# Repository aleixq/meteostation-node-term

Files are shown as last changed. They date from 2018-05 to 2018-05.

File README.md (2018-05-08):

# MeteoStation-Node-Term
This is a Project to create a weather station, it's based in code from sparkfun by Nathan Seidle, but expanded to make it work to provide a station with its lcd display to show the sensors values. This station also send via serial the sensors data in JSON to a NodeMCU - *the Meteonode* -and it provides a web server to read the data in json (at http://meteoNodeIP:meteoNodePort/getMeteoData), a second nodemcu  - *the Meteoterm* - will connect to the server and will obtain de the sensors values and with these it will calculate some extra information, forecast, pressure history, wind in a polar graphic... And it will be displayed in a tft small screen.

The wifi credentials must be provided in meteonode and meteoterm (an example is provided on each project as wifi-credentials.h.example) move to copy to wifi-credentials.h on each project before builing and uploading the projects.

I build this projects using arduino-makefile from http://hardwarefun.com/tutorials/compiling-arduino-sketches-using-makefile instead of arduino IDE, with some tweaks it can be easy to be ran by IDE.

# Meteostation
BOM:
- Arduino Mega.
- BME280 Pressure sensor.
- SPARKFUn Weather Shield (for wind and rain as pressure temps was a pain...).
- LCD 20x4.

# Meteonode
BOM:
- NodeMCU (linked via serial to MEGA).
- Bidirectional level shifter(3V3 <--> 5V). (to make 5V arduino mega serial pins be reduced to 3V3).

# Meteoterm
BOM:
- NodeMCU 
- ILI9341 Touch screen.
Explained in respective project directory.

# TODO
Add 3d freecad files for cases. 
Add fritzing connections.
Move functions to own classes(as is separated) (yes i have to fulfill the transition from ino to cpp, but this project once upon a time was a simple ino file).
Use E-Ink display in meteoterm to save energy.
Use battery on meteoterm.
Transition to a less energy drainer putting nodemcu in sleep mode, and relax the polling.

# Kudos
big kudos to authors of: 
- Great bme library, from which I have copy some code https://github.com/finitespace/BME280 .
- Another zambretti based forecaster https://github.com/hes19073/hesweewx/blob/0415b182d2318f85cefb9727da630fbe42fab9c9/bin/user/forecast.py 
- A great forecaster https://github.com/fandonov/weatherstation , including zambretti interpretation.
- Zambretti js code of http://www.beteljuice.co.uk/zambretti/forecast.html (the inspiration and the basis of the forecast algorithm in meteoterm.
- Zambretti first forecaster: https://web.archive.org/web/20110610213848/http://www.meteormetrics.com/zambretti.htm
- Ntp code from https://www.geekstips.com/arduino-time-sync-ntp-server-esp8266-udp/
- Great timelib libs: https://github.com/PaulStoffregen/Time 
- Great GFX code from adafruit https://learn.adafruit.com/adafruit-gfx-graphics-library

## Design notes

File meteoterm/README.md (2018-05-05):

#Terminal d'estació meterològica.
La unitat té un historial de pressió (12hores/4preses) registrada a la memòria
Flash. Quan es reinicia hauria de llegir l'historial de la memòria, així que
no hi ha problema en reiniciar.
L'historial serveix per fer un càlcul de la predicció seguint l'algorisme de
Zambretti.
## Funcionament
A intervals regulars (defecte 5seg). Fa una consulta a l'adreça de l'estació
meteorològica (mdns,hostname=meteonode) que s'hagi descobert a la mateixa xarxa,
la consulta que fa és (http://meteoNodeIP:meteoNodePort)/getMeteoData?time=now.
Un cop feta la consulta el meteonode envia les dades que els sensors han llegit,
en json, ho rebem i renderitzem els valors a la pantalla. Quan hem acabat guardo
a la memòria flash la història, hagi canviat o no.

## Hora
l'agafa de NTP cada 5 minuts.

## Historial:
Inici -> [Llegeix de la flash els registres guardats] ->
Demana lectura al meteonode -> tenint la Lectura comprova si la que hi ha a la
flash(fitxer history.json)és anterior a un interval (per defecte 12h/4samples
això és 3/6/9/12), si ho és fes correr tot l'historial una posició:
Clau    Valor
3       Descarta
2       valor de 1
1       valor de 0
0       valor llegit

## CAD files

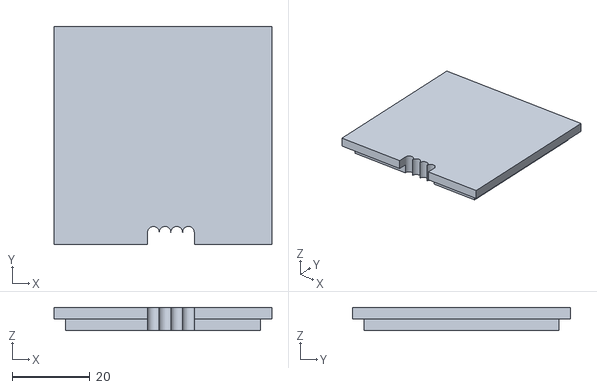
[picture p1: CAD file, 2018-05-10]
3D-dissenys/meteonode-lid.stl
56.0 x 56.0 x 6.00

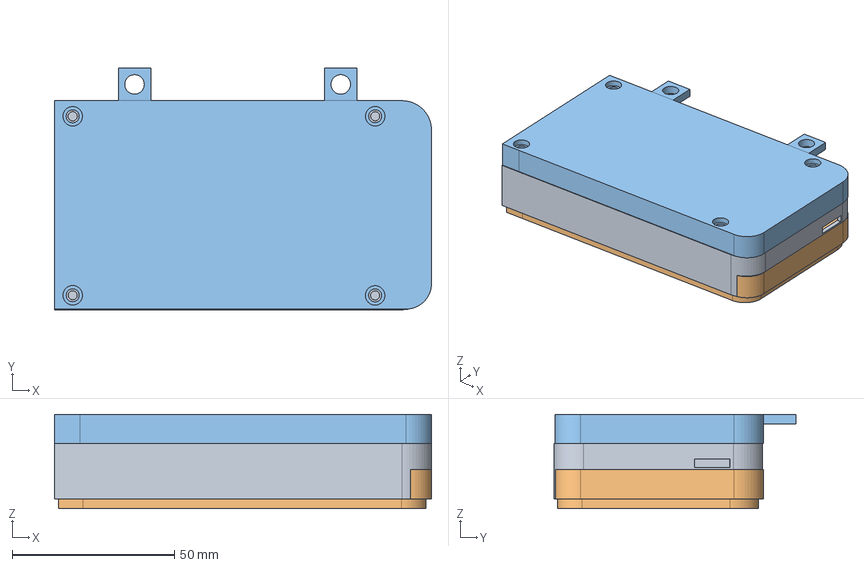
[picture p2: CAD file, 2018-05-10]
3D-dissenys/meteostation-lcd.fcstd
116.0 x 74.4 x 29.0 mm
Fusion-End

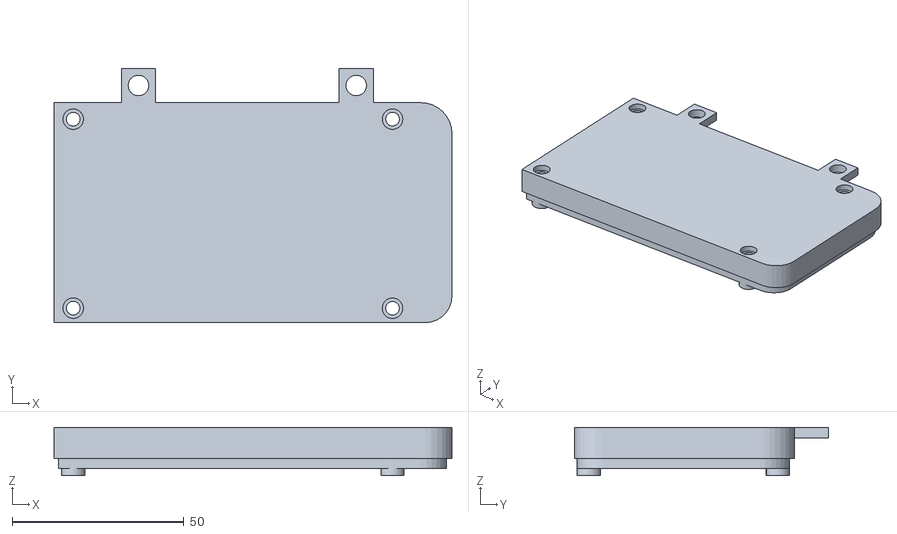
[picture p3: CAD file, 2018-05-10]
3D-dissenys/meteostation-lcd-backplate.stl
116.0 x 74.1 x 14.0

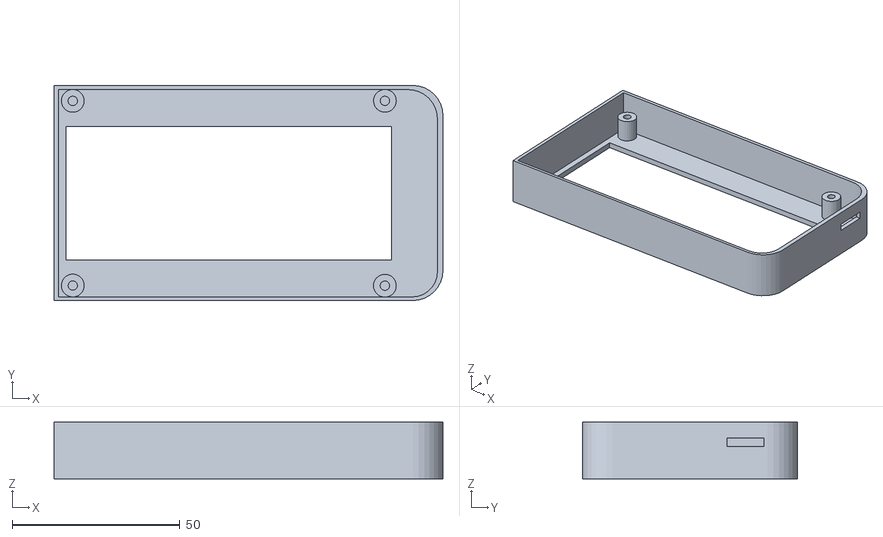
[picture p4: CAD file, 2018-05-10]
3D-dissenys/meteostation-lcd-body.stl
116.0 x 64.2 x 17.0

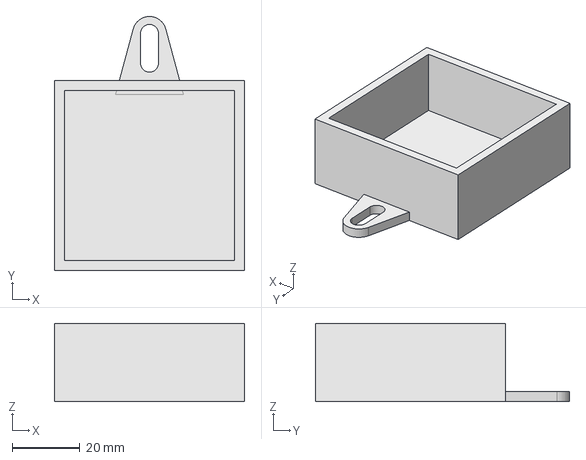
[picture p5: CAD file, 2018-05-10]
3D-dissenys/meteonode-box.fcstd
56.0 x 74.8 x 23.0 mm

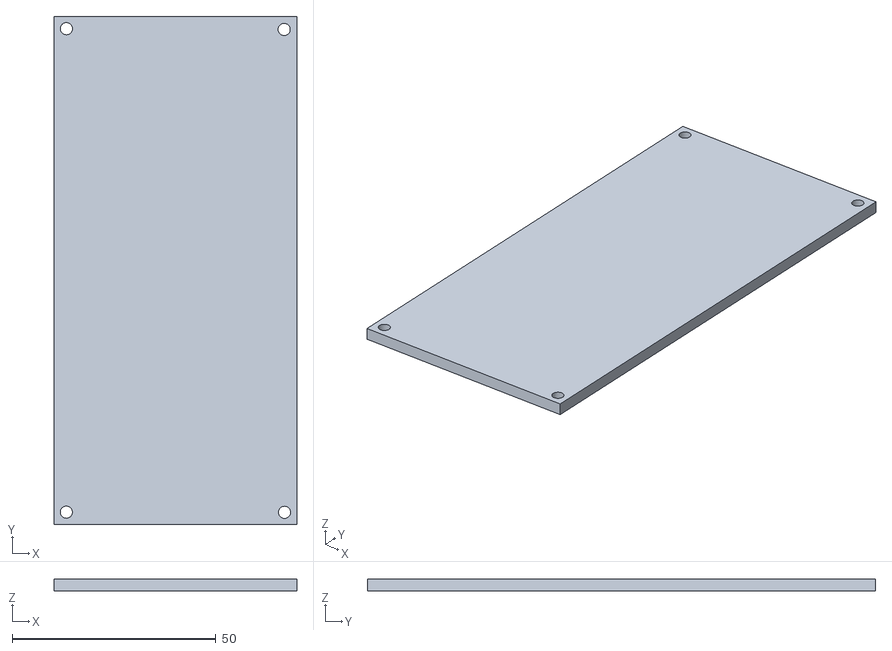
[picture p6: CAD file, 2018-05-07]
3D-dissenys/meteoterm_box_back.stl
59.6 x 124.7 x 3.00

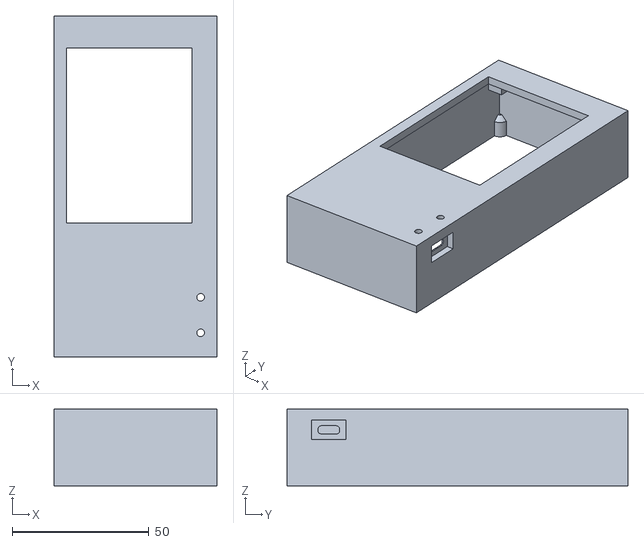
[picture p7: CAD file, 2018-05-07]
3D-dissenys/meteoterm_box.stl
59.6 x 124.7 x 28.0

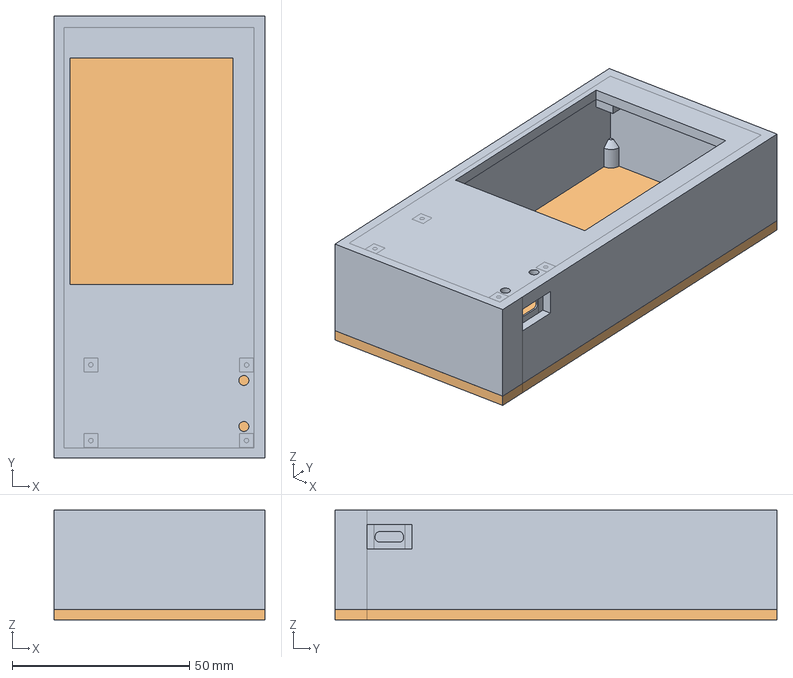
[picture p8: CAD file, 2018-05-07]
3D-dissenys/meteoterm--ili79341-Nodemcu.fcstd
59.6 x 124.7 x 31.0 mm
Fusion-Box (Mirror #1)
Backplate

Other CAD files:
3D-dissenys/meteonode-box.stl

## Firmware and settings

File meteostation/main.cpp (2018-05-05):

/*
 Weather Shield Station
 By: Aleix Quintana Alsius
 Date: May 5th, 2018
 Weather shield to serial to comunicate with esp8266 to propagate data
 License: This code is public domain but you buy me a beer if you use this and we meet someday (Beerware license).

 Much of this is based on Mike Grusin's USB Weather Board code: https://www.sparkfun.com/products/10586, and later Nathan Seidle

 This code reads all the various sensors (wind speed, direction, rain gauge, humidty, pressure, light, batt_lvl)
 and reports it over the serial comm port. This can be easily routed to an datalogger (such as OpenLog) or
 a wireless transmitter (such as Electric Imp).

 Measurements are reported once a second but windspeed and rain gauge are tied to interrupts that are
 calcualted at each report.

 This example code assumes the GPS module is not used.

*/
#include <SoftwareSerial.h>
#include <Arduino.h>
#include <Wire.h>
#include "Screen.h"
#include "Meteo.h"

const byte rxPin = 15; // Wire this to Tx Pin of ESP8266
const byte txPin = 14; // Wire this to Rx Pin of ESP8266

// We'll use a software serial interface to connect to ESP8266
SoftwareSerial ESP8266 (rxPin, txPin);




#define FAKE_WINDIRQ  //TODO , IRQ REMAP  because we use CC3000, look for "TODO" to watch how.
int DEBUG = 1;      // DEBUG counter; if set to 1, will write values back via serial


#include <avr/wdt.h> //We need watch dog for this program


#define IDLE_TIMEOUT_MS  3000 // Amount of time to wait (in milliseconds) with no data
// received before closing the connection.  If you know the server
// you're accessing is quick to respond, you can reduce this value.

#define REFRESH_DATA 1000
#define REFRESH_LCD 5000

/** SCREEN VARS **/
long lastTimeLcd; //The millis lcd counter
//Create lcd object with 0x3F direction -> 20 columns x 4 rows
LiquidCrystal_I2C lcd(0x3F, 20, 4);
//LiquidCrystal_I2C lcd(0x27,16,2);

#define LCD_ROWS_TOPRINT 4
String lcdOut[LCD_ROWS_TOPRINT] = { "T-Pr-W", "VENT", "H-PL", "conMSG" };
int curScreen = 0;
/** END OF SCREEN VARS **/


/* WEATHER VARS */
// Pressure sensor
Adafruit_BME280 bme;
//Hardware pin definitions
//-=-=-=-=-=-=-=-=-=-=-=-=-=-=-=-=-=-=-=-=-=-=-=-=-=-=-=-=
// digital I/O pins
const byte WSPEED = 3;
//const byte WSPEED = 19; //if we need any sensor using hardware IRQ(as wifi cc3000) we can change the PIN here.
//const byte WSPEED = 4; // if we want to simulate the IRQ define a fake irq.
const byte RAIN = 2;
const byte STAT1 = 7;
const byte STAT2 = 8;

// analog I/O pins
const byte REFERENCE_3V3 = A3;
const byte LIGHT = A1;
const byte BATT = A2;
const byte WDIR = A0;
//-=-=-=-=-=-=-=-=-=-=-=-=-=-=-=-=-=-=-=-=-=-=-=-=-=-=-=-=

//Global Variables
//-=-=-=-=-=-=-=-=-=-=-=-=-=-=-=-=-=-=-=-=-=-=-=-=-=-=-=-=
long lastTime; //The millis counter
byte seconds; //When it hits 60, increase the current minute
byte seconds_2m; //Keeps track of the "wind speed/dir avg" over last 2 minutes array of data
byte minutes; //Keeps track of where we are in various arrays of data
byte minutes_10m; //Keeps track of where we are in wind gust/dir over last 10 minutes array of data

long lastWindCheck = 0;
volatile long lastWindIRQ = 0;
volatile byte windClicks = 0;

//We need to keep track of the following variables:
//Wind speed/dir each update (no storage)
//Wind gust/dir over the day (no storage)
//Wind speed/dir, avg over 2 minutes (store 1 per second)
//Wind gust/dir over last 10 minutes (store 1 per minute)
//Rain over the past hour (store 1 per minute)
//Total rain over date (store one per day)

byte windspdavg[120]; //120 bytes to keep track of 2 minute average

#define WIND_DIR_AVG_SIZE 120
int winddiravg[WIND_DIR_AVG_SIZE]; //120 ints to keep track of 2 minute average
float windgust_10m[10]; //10 floats to keep track of 10 minute max
int windgustdirection_10m[10]; //10 ints to keep track of 10 minute max
volatile float rainHour[60]; //60 floating numbers to keep track of 60 minutes of rain

//These are all the weather values that wunderground expects:
int winddir = 0; // [0-360 instantaneous wind direction]
float windspeedkph = 0; // [kph instantaneous wind speed
float windgustkph = 0; // [kph current wind gust, using software specific time period]
int windgustdir = 0; // [0-360 using software specific time period]
float windspdkph_avg2m = 0; // [mph 2 minute average wind speed mph]
int winddir_avg2m = 0; // [0-360 2 minute average wind direction]
float windgustkph_10m = 0; // [mph past 10 minutes wind gust mph ] //TODO ->move to km/h
int windgustdir_10m = 0; // [0-360 past 10 minutes wind gust direction]

float city_meters_above_sea = 280.0+10.0; //TERRASSA + pisos
float humitat = 0; // [%]
float temperaturaf = 0; // [temperature F]
float temperaturac = 0; //  [temperature C]
float dew_point;
float barometer_raw = 0.0;
float barometer_mB = 1020.0;
float pressio = 0;

float rainin = 0; // [rain inches over the past hour)] -- the accumulated rainfall in the past 60 min
volatile float dailyrainin = 0; // [rain inches so far today in local time]

float batt_lvl = 11.8; //[analog value from 0 to 1023]
float light_lvl = 455; //[analog value from 0 to 1023]

// volatiles are subject to modification by IRQs
volatile unsigned long raintime, rainlast, raininterval, rain;

/* END OF WEATHER VARS */


namespace
{
  template<typename Any>
  /**
   Look if DEBUG is on and output to std out.
  */
  void debugit(Any value) {
    if (DEBUG) {
      Serial.println(value);
    }
  }
}

void setup(void)
{
  wdt_reset(); //Pet the dog
  wdt_disable(); //We don't want the watchdog during init

  // Init LCD
  lcd.init();
  lcd.init();
  lcd.backlight();
  // Write to LCD.
  lcd.setCursor(0, 0);
  lcd.print("Starting");
  lcd.setCursor(0, 1);
  lcd.print("MeteoStation...");
  /**
     BLINK TO SHOW IT'S WORKING
  */
  pinMode(STAT1, OUTPUT); //Status LED Blue
  blinking();

  Serial.begin(115200);
  ESP8266.begin(9600); // Change this to the baudrate used by ESP8266
  delay(1000); // Let the module self-initialize

  /*
     2- WEATHER SETUP!
  */

  pinMode(STAT1, OUTPUT); //Status LED Blue
  pinMode(STAT2, OUTPUT); //Status LED Green

  pinMode(WSPEED, INPUT_PULLUP); // input from wind meters windspeed sensor
  pinMode(RAIN, INPUT_PULLUP); // input from wind meters rain gauge sensor

  pinMode(REFERENCE_3V3, INPUT);
  pinMode(LIGHT, INPUT);

  //Configure the pressure sensor
  // Barometer bme280 fent servir adafruit llavors hem de canviar l'adreca i2c de 0x77 a 0x76.
  // If using Sparkfun then we must edit the library SparkFun_BME280_Arduino_Library-2.0.0/src/SparkFunBME280.cpp and define settings.I2CAddress = 0x76;
  if (!bme.begin(0x76))
  {
    Serial.println("Error! No BMP Sensor Detected!!!");
    while (1);
  }

  seconds = 0;
  lastTime = millis()-REFRESH_DATA; //Force get sensors upon Start
  lastTimeLcd = millis()-REFRESH_LCD; //Force send data upon Start

  // attach external interrupt pins to IRQ functions
  attachInterrupt(digitalPinToInterrupt(RAIN), rainIRQ, FALLING);
  attachInterrupt(digitalPinToInterrupt(WSPEED), wspeedIRQ, FALLING);

  // turn on interrupts
  interrupts();
}


void loop()
{
  wdt_reset(); //Pet the dog
  /* SENSORS */
  //Keep track of which minute it is
  if (millis() - lastTime >= REFRESH_DATA)
  {
    digitalWrite(STAT1, HIGH); //Blink stat LED

    debugit("Sensors fire!!");
    lastTime = millis();

    //Take a speed and direction reading every second for 2 minute average
    if (++seconds_2m > 119) seconds_2m = 0;

    //Calc the wind speed and direction every second for 120 second to get 2 minute average
    float currentSpeed = windspeedkph;
    int currentDirection = get_wind_direction();
    windspdavg[seconds_2m] = (int)currentSpeed;
    winddiravg[seconds_2m] = currentDirection;

    //Check to see if this is a gust for the minute
    if (currentSpeed > windgust_10m[minutes_10m])
    {
      windgust_10m[minutes_10m] = currentSpeed;
      windgustdirection_10m[minutes_10m] = currentDirection;
    }

    //Check to see if this is a gust for the day
    if (currentSpeed > windgustkph)
    {
      windgustkph = currentSpeed;
      windgustdir = currentDirection;
    }

    if (++seconds > 59)
    {
      seconds = 0;

      if (++minutes > 59) minutes = 0;
      if (++minutes_10m > 9) minutes_10m = 0;

      rainHour[minutes] = 0; //Zero out this minute's rainfall amount
      windgust_10m[minutes_10m] = 0; //Zero out this minute's gust
    }

    //Check to see if there's been lighting
    #ifdef FAKE_WINDIRQ
    if (digitalRead(WSPEED) == HIGH)
    {
      //We've got something!
      wspeedIRQ();
    }
    #endif

    //Report all readings every second
    calcWeather();
    digitalWrite(STAT1, LOW); //Turn off stat LED
  }
  if (millis()- lastTimeLcd >= REFRESH_LCD){
    digitalWrite(STAT2, HIGH); //Start sending Data via serial GREEN LED ON
    //Send data to Serial
    debugit("We got data, start connecting");
    lastTimeLcd = millis();

    // Ship it!
    // To Standard out
    String strOut = String(
                      "[{ \"dew_point\": "  + String(dew_point) +
                      ", \"temperatura\" : " + String(temperaturac) +
                      ", \"pressio\" : " + String(pressio) +
                      ", \"humitat\" : " + String(humitat) +
                      ", \"wind_speed\" : " + String(windspeedkph) +
                      ", \"wind_deg\" : " + String(winddir) +
                      ", \"rain_1h\" : " + String(rainin) +
                      ", \"rain_24h\" : " + String(dailyrainin) +
                      "}]");
    ESP8266.println(strOut);

    debugit(strOut);

    lcdOut[0] = String(
                  "DP"  + String(dew_point) +
                  " " + String(temperaturac) + (char)223);
    lcdOut[1] = String(
                  String(pressio) + "h " +
                  String(humitat) + "%" );
    lcdOut[2] = String(
                  "VENT: " + String(windspeedkph) +
                  " - " + String(winddir) + (char)223);
    lcdOut[3] = String(
                  "P 1h:" + String(rainin) +
                  " 24h:" + String(dailyrainin) +
                  "");

    debugit("--TODO CHECK get_wind_speed and get_windsepeed_v2 (pass to ms) --");
    debugit("Upload complete");

    /* Read data until either the connection is closed, or the idle timeout is reached.
    */
    Serial.flush();


    debugit("SUCCESS! ");
    digitalWrite(STAT2, LOW); //Success!! Turn off GREEN LED
    nextScreen();
  }
  //delayScroll(74); //(5+2.4 seconds)
  //lpDelay(1200); // Low Power Delay. Value of 4=1sec, 40=10sec, 1200=5min --If battery, send every 5 min.
}

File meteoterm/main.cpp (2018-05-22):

#include <TimeLib.h>

#include <Arduino.h>
#include <SPI.h>

#include "wifi-credentials.h"
#include <Adafruit_ILI9341esp.h>
#include <Adafruit_GFX.h>
#include <XPT2046.h>
#include <ESP8266WiFi.h>
#include <ESP8266WiFiMulti.h>
#include <ESP8266HTTPClient.h>
#include <ESP8266mDNS.h>
#include <ArduinoJson.h>
#include <FS.h>
#include <WiFiUdp.h>

#include "weathertake.h"
#include "WeatherLogger.h"
#include "layout.h"
#include "Forecaster.h"
#include "wu_icons.h";



ESP8266WiFiMulti WiFiMulti;

// Modify the following two lines to match your hardware
// Also, update calibration parameters below, as necessary

// For the esp shield, these are the default.
#define TFT_DC 2
#define TFT_CS 15

// CS for SD reader
#define SD_CS 4
File f; // main history file
File fb; // secondary history file
int historyBackupFrequency= 600;
unsigned long lastHistoryBackup=0;

//char meteoNode[16] = {0};
IPAddress meteoNode ;
int meteoNodePort = 80;

Adafruit_ILI9341 tft = Adafruit_ILI9341(TFT_CS, TFT_DC);
XPT2046 touch(/*cs=*/ 4, /*irq=*/ 5);

// Discover and refresh frequency in s
int NEXT_REFRESH_IN = 0; //int holding when will occur the next refresh
int REFRESH_FREQ = 5;
long lastSecond; //The seconds counter to see when a second rolls by


// # Weather VARS
float humitat = 0; // [%]
float temperaturac = 0; //  [temperature C]
float dewPoint;
float barometer_mB = 1020.0;
float pressio = 0;
float windspeedkph = 0;
int windgustdir = 0; // [0-360 using software specific time period]
float rainin = 0; // [rain inches over the past hour)] -- the accumulated rainfall in the past 60 min
volatile float dailyrainin = 0; // [rain inches so far today in local time]

time_t timeNow  = 1524259887;

// # Forecast Vars
const int older_sample = 12;
const int samples = 4;
WeatherTake history[samples];

const bool N_HEMISPHERE = true; //north_hemisphere
#define FORECASTARRAYSIZE 27

char* forecast[FORECASTARRAYSIZE] = {
    "Settled fine", //0
    "Bon temps",
    "Becoming fine",
    "Fine, becoming\n less settled",
    "Fine, possible\n showers", //5
    "Fairly fine,\n improving",
    "Fairly fine,\n possible showers early",
    "Fairly fine,\n showery later",
    "Showery early,\n improving",
    "Changeable, mending", //10
    "Fairly fine,\n showers ",//likely",//ly",
    "Rather unsettled\n clearing later",
    "Unsettled, probably\n improving",
    "Showery, bright\n intervals",
    "Showery, becoming\n less settled", //15
    "Changeable, some\n rain",
    "Unsettled, short\n fine intervals",
    "Unsettled, rain\n later",
    "Unsettled, some\n rain",
    "Mostly very\n unsettled", //20
    "Occasional rain,\n worsening",
    "Rain at times,\n very unsettled",
    "Rain at frequent\n intervals",
    "Rain, very\n unsettled",
    "Stormy, may\n improve", //25
    "Stormy, much rain"
};
// equivalents of Zambretti 'dial window' letters A - Z
int rise_options[FORECASTARRAYSIZE]  = {25,25,25,24,24,19,16,12,11,9,8,6,5,2,1,1,0,0,0,0,0,0} ;
int steady_options[FORECASTARRAYSIZE] = {25,25,25,25,25,25,23,23,22,18,15,13,10,4,1,1,0,0,0,0,0,0} ;
int fall_options[FORECASTARRAYSIZE] =  {25,25,25,25,25,25,25,25,23,23,21,20,17,14,7,3,1,1,1,0,0,0} ;

// # Layout Vars
int margin = 5;
int rowSize = 0;
int columnSize = 0;

// # TIME VARS


// NTP Servers:
static const char ntpServerName[] = "pool.ntp.org";
//static const char ntpServerName[] = "time.nist.gov";
//static const char ntpServerName[] = "time-a.timefreq.bldrdoc.gov";
//static const char ntpServerName[] = "time-b.timefreq.bldrdoc.gov";
//static const char ntpServerName[] = "time-c.timefreq.bldrdoc.gov";

const int timeZone = 2;     // Central European Time
//const int timeZone = -5;  // Eastern Standard Time (USA)
//const int timeZone = -4;  // Eastern Daylight Time (USA)
//const int timeZone = -8;  // Pacific Standard Time (USA)
//const int timeZone = -7;  // Pacific Daylight Time (USA)

const int NTP_PACKET_SIZE = 48; // NTP time is in the first 48 bytes of message
byte packetBuffer[NTP_PACKET_SIZE]; //buffer to hold incoming & outgoing packets

// # Connection VARS
WiFiUDP Udp;
unsigned int localPort = 8888; // local port to listen for UDP packets
boolean WiFiReturns();

time_t getNtpTime();
void sendNTPpacket(IPAddress &address);

// # File VARS
String fileRead(String);
void fsInit(void);




void setup() {
    delay(1000);

    Serial.begin(115200);
    // Initialize Filesystem
    Serial.println("Opening SPIFFS");
    fsInit();

    SPI.setFrequency(ESP_SPI_FREQ);

    tft.begin();
    touch.begin(tft.width(), tft.height());  // Must be done before setting rotation
    tft.setRotation(3);
    rowSize = tft.height() / 5;
    columnSize = (tft.width() - margin) / 6;
    Serial.print("tftx ="); Serial.print(tft.width()); Serial.print(" tfty ="); Serial.println(tft.height());
    tft.fillScreen(ILI9341_BLACK);
    // Replace these for your screen module
    touch.setCalibration(209, 1759, 1775, 273); // it's set in portrait
    touch.setRotation(touch.ROT270);

    // WIFI PART
    // We start by connecting to a WiFi network

    Serial.println();
    Serial.println();
    Serial.print("Connecting to ");
    Serial.println(ssid);

    /* Explicitly set the ESP8266 to be a WiFi-client, otherwise, it by default,
     would try to act as both a client and an access-point and could cause
     network-issues with your other WiFi-devices on your WiFi-network. */
    WiFi.mode(WIFI_STA);
    WiFiMulti.addAP(ssid, password);

    while (WiFiMulti.run() != WL_CONNECTED) {
        delay(500);
        Serial.print(".");
    }

    Serial.println("");
    Serial.println("WiFi connected");
    Serial.println("IP address: ");
    Serial.println(WiFi.localIP());
    Serial.println();

    if (!MDNS.begin("terminalMeteo")) {
        Serial.println("Error setting up MDNS responder!");
    }
    Serial.println("Sending mDNS query");
    int n = MDNS.queryService("meteo", "tcp"); // Send out query for esp tcp services
    Serial.println("mDNS query done");
    while (n == 0) {
        Serial.println("no services found");
        n = MDNS.queryService("meteo", "tcp"); // Send out query for esp tcp services
        Serial.println("mDNS re-query done");
        delay(2000);
    }
    if (n > 0) {
        Serial.print(n);
        Serial.println(" service(s) found");
        for (int i = 0; i < n; ++i) {
            // Print details for each service found
            Serial.print(i + 1);
            Serial.print(": ");
            Serial.print(MDNS.hostname(i));
            Serial.print(" (");
            Serial.print(MDNS.IP(i));
            Serial.print(":");
            Serial.print(MDNS.port(i));
            Serial.println(")");
            if (MDNS.hostname(i) == "meteonode") {
                // Stop on first neteonode found.
                meteoNode = MDNS.IP(i);
                meteoNodePort = MDNS.port(i);
                break;
            }
        }
    }
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

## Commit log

2018-05-07 Add meteoterm 3d design(freecad and stl)
    [meteoterm--ili79341-Nodemcu.fcstd, meteoterm_box.stl, meteoterm_box_back.stl]
2018-05-08 Fix History array shifting each REFRESH_FREQ, added notes in code
    [WeatherLogger.cpp, main.cpp]
2018-05-09 Add meteostation lcd 3d design.
    [meteostation-lcd-backplate.stl, meteostation-lcd-body.stl, meteostation-lcd.fcstd]
2018-05-10 Adding Meteonode box design, fix meteostation lcd box
    [meteonode-box.fcstd, meteonode-box.stl, meteonode-lid.stl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]
2018-05-22 Fix wind direction bad values
    [main.cpp]
